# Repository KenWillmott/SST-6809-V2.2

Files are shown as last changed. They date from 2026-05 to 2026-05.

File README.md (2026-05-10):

# SST-6809-V2.2
This is the working repository for the most current and only recommended version of the SST-6809.
It contains all of the files and reference documents, and some documentation. However, the full documentation set will be hosted elsewhere, location is yet to be determined. For now, you can follow the documentation in the old repo "SST-6809" which is mostly concordant with this new version.

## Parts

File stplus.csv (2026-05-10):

Id | Designator | Footprint | Quantity | Designation | Supplier and ref
1 | U10 | DIP-8_W7.62mm_Socket_LongPads | 1 | DS1210
2 | C9,C5,C14,C11,C3,C13,C8,C4,C6,C7 | C_Disc_D8.0mm_W2.5mm_P5.00mm | 10 | 100nF
3 | JP3,JP4,JP1 | PinHeader_1x03_P2.54mm_Vertical | 3 | Jumper_3_Bridged12
4 | U3 | PLCC-32_THT-Socket | 1 | SST39SF010
5 | RN1 | R_Array_SIP9 | 1 | 4.7k
6 | X1 | Oscillator_DIP-8 | 1 | CXO_DIP8
7 | C10 | C_Disc_D9.0mm_W2.5mm_P5.00mm | 1 | 10uF
8 | C1,C2 | C_Disc_D8.0mm_W2.5mm_P5.00mm | 2 | 20pF
9 | U4 | DIP-20_W7.62mm_LongPads | 1 | 74HCT273
10 | J4 | PinHeader_2x03_P2.54mm_Vertical | 1 | Conn_02x03_Odd_Even
11 | Y1 | Crystal_HC18-U_Vertical | 1 | 8.0 MHz
12 | J2 | TerminalBlock_Phoenix_PT-1,5-2-5.0-H_1x02_P5.00mm_Horizontal | 1 | Screw_Terminal_01x02
13 | C12 | C_Disc_D9.0mm_W2.5mm_P5.00mm | 1 | 100nF
14 | H4,H2,H1,H3 | MountingHole_3.2mm_M3_Pad | 4 | MountingHole_Pad
15 | J5 | PinHeader_2x07_P2.54mm_Vertical | 1 | Conn_02x07_Odd_Even
16 | U2 | DIP-24_W15.24mm_LongPads | 1 | MC68B50
17 | U8 | DIP-16_W7.62mm_LongPads | 1 | 74HCT138
18 | R1 | R_Axial_DIN0207_L6.3mm_D2.5mm_P10.16mm_Horizontal | 1 | 10k
19 | JP2 | PinHeader_2x01_P2.54mm_Vertical | 1 | VBAT
20 | D1 | LED_D3.0mm | 1 | STAT
21 | SW1 | SW_PUSH_6mm_H5mm | 1 | Reset
22 | U12 | DIP-16_W7.62mm_LongPads | 1 | 74HCT139
23 | U6 | DIP-32_W15.24mm_LongPads | 1 | AS6C4008-55PCN
24 | J1 | PinHeader_1x06_P2.54mm_Vertical | 1 | Conn_01x06_Pin
25 | J6 | PinSocket_2x20_P2.54mm_Vertical | 1 | Conn_02x20_Odd_Even
26 | U1 | DIP-40_W15.24mm_LongPads | 1 | MC68B09
27 | U9 | TO-92L_Inline | 1 | DS1233
28 | U5 | DIP-14_W7.62mm_LongPads | 1 | 74HCT02
29 | R2 | R_Axial_DIN0207_L6.3mm_D2.5mm_P10.16mm_Horizontal | 1 | 4.7k
30 | D2 | D_DO-35_SOD27_P7.62mm_Horizontal | 1 | 1N4148
31 | U11 | DIP-14_W7.62mm_LongPads | 1 | 74HCT20
32 | J3 | PinHeader_1x04_P2.54mm_Vertical | 1 | Conn_01x04_Pin
33 | U7 | TO-92L_Inline | 1 | DS1813
34 | D3 | LED_D3.0mm | 1 | PWR
35 | BT1 | BatteryHolder_Keystone_103_1x20mm | 1 | 3.0V

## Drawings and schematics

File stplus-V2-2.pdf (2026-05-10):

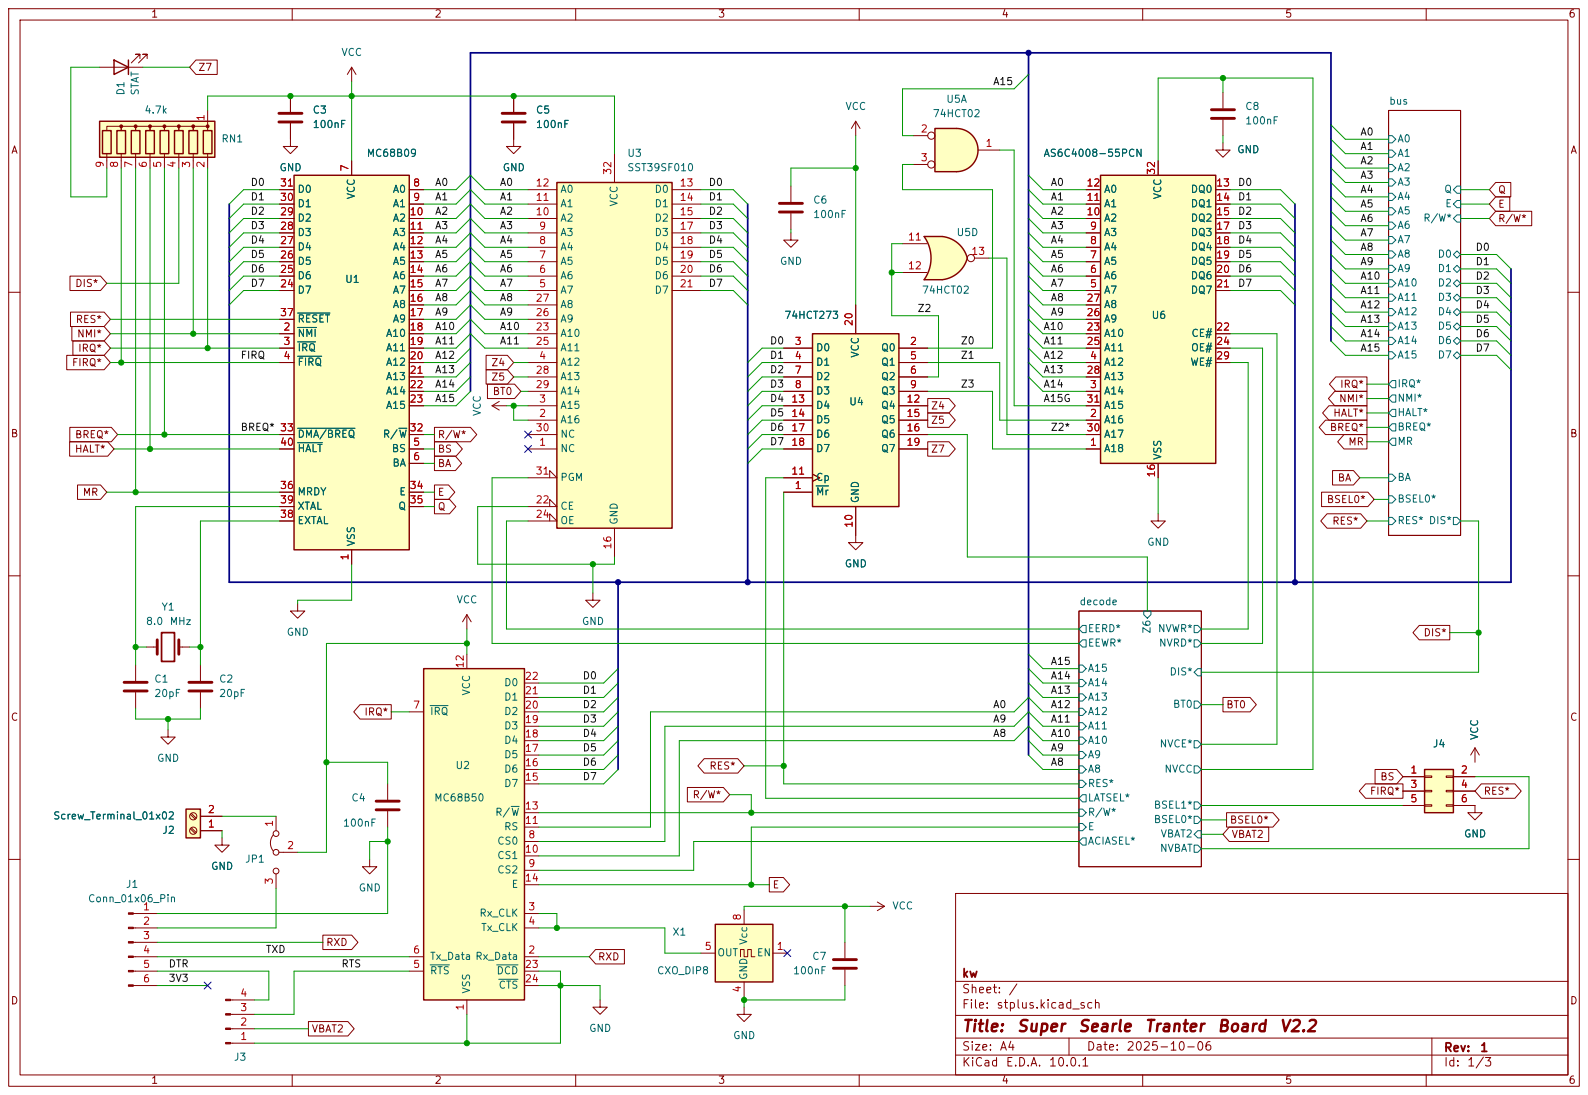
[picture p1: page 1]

Sheet: /
File: stplus.kicad_sch
Title: Super Searle Tranter Board V2.2

Size: A4 | Rev: 1
KiCad E.D.A. 10.0.1 | Id: 1/3

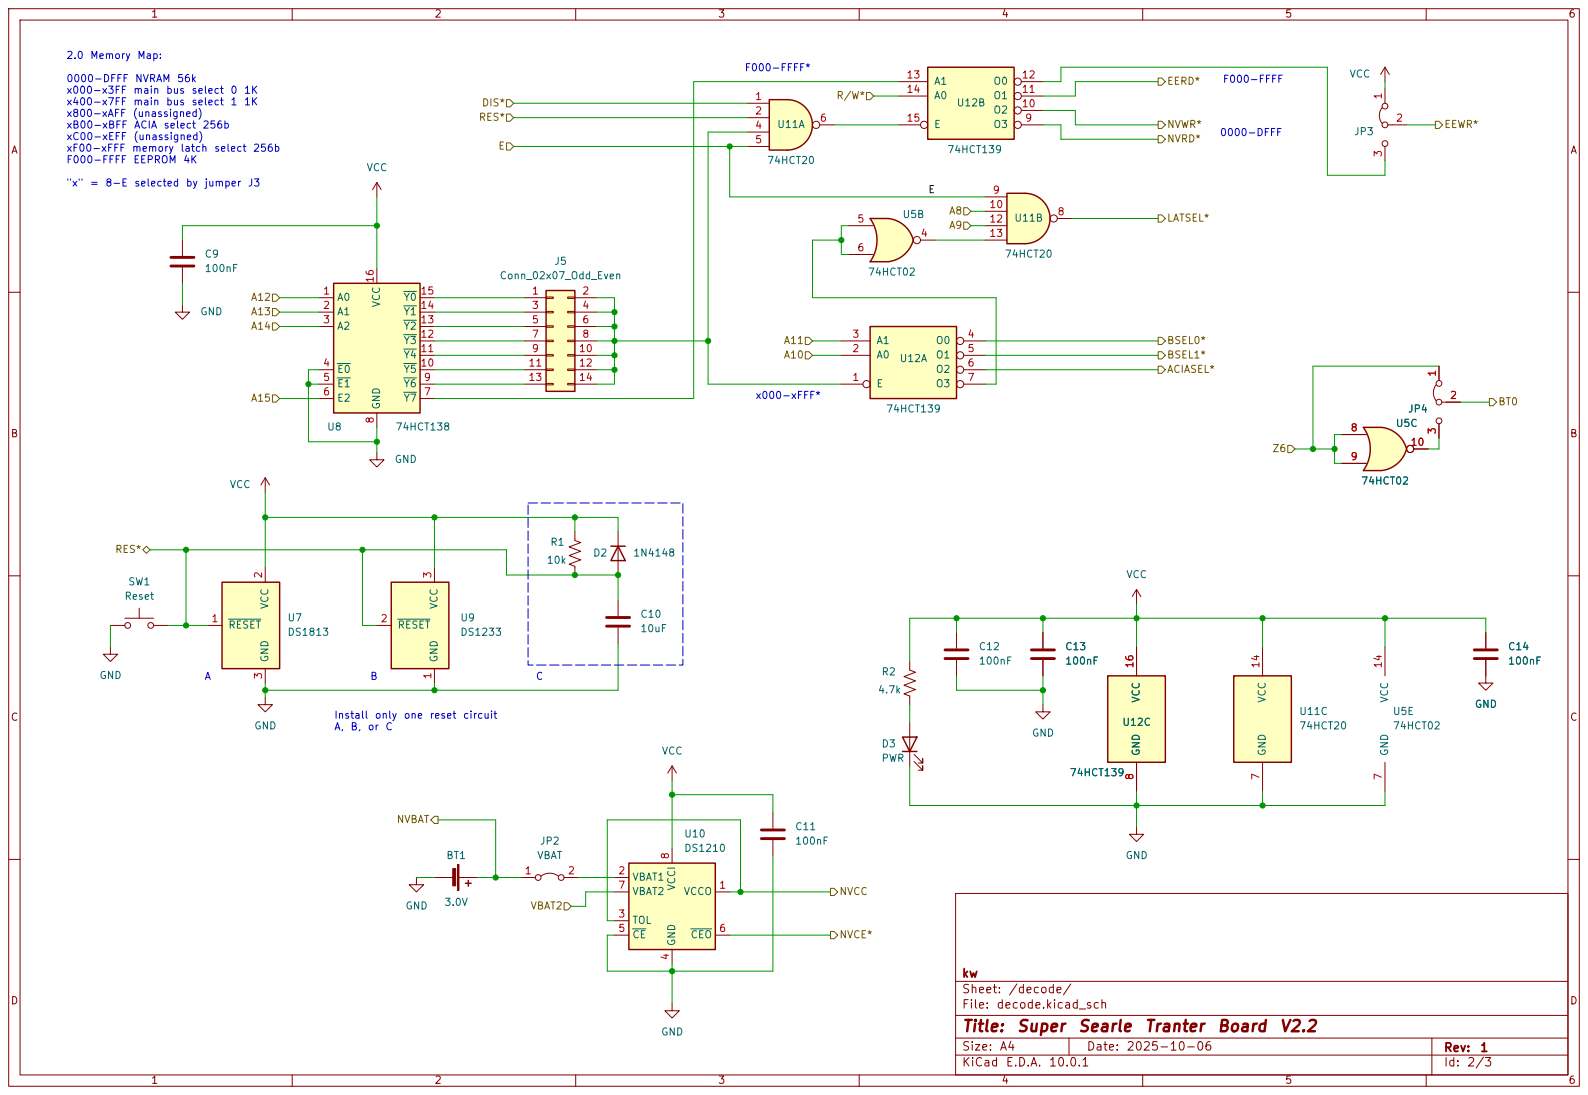
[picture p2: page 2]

2.0 Memory Map: 0000-DFFF NVRAM 56k

x000-x3FF main bus select 0 1K
x400-x7FF main bus select 1 1K
x800-xAFF (unassigned) xB00-xBFF ACIA select 256b

xC00-xEFF (unassigned) xF00-xFFF memory latch select 256b

Install only one reset circuit A, B, or C

Sheet: /decode/
File: decode.kicad_sch
Title: Super Searle Tranter Board V2.2

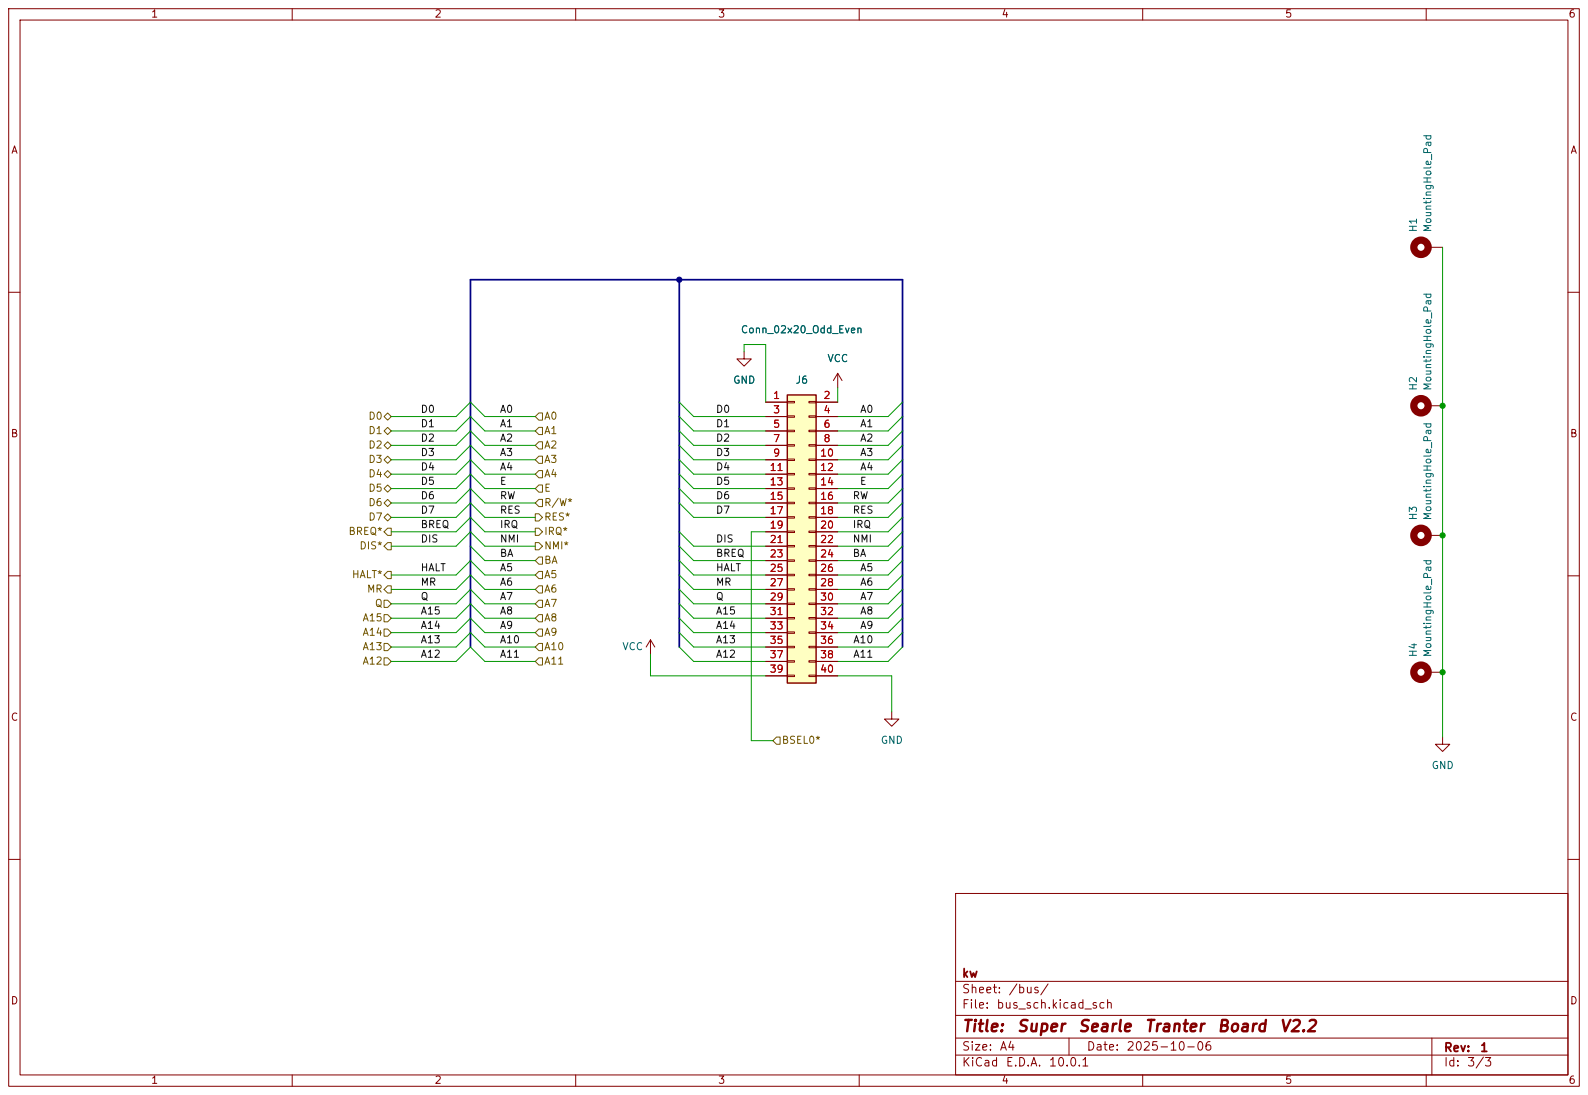
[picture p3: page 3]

Sheet: /bus/
File: bus_sch.kicad_sch
Title: Super Searle Tranter Board V2.2

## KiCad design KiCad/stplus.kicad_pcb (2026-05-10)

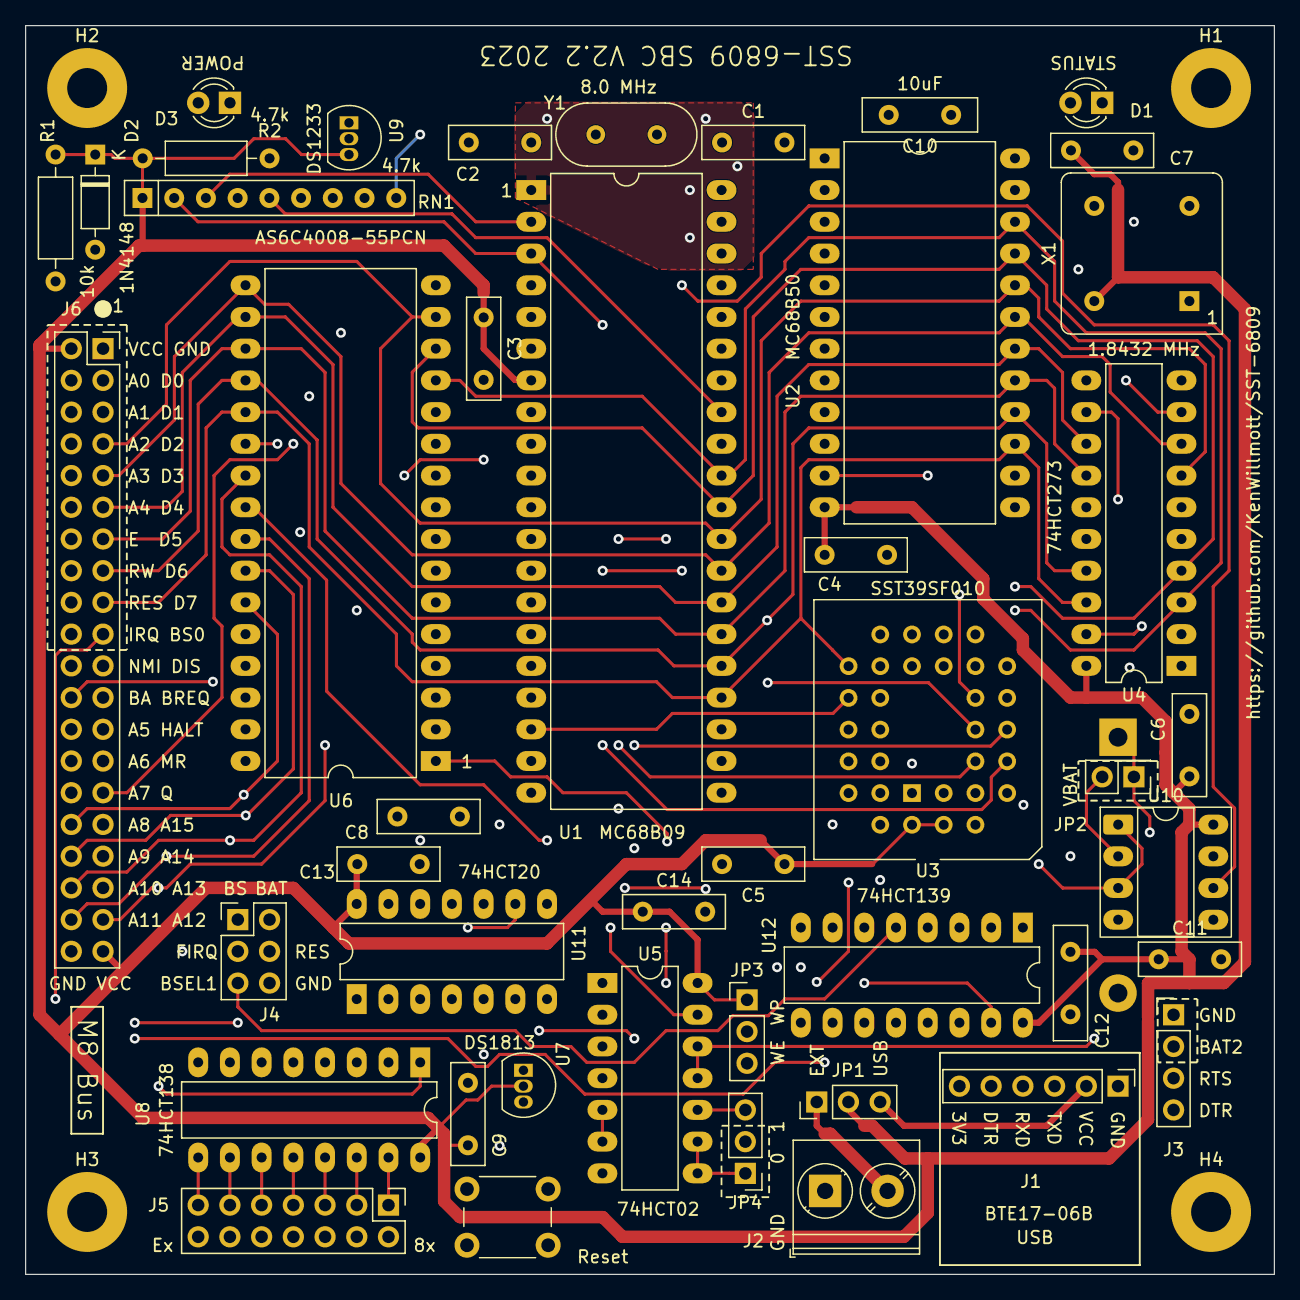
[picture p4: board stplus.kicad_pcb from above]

Board: 4 copper layers, 100.0 x 100.0 mm, 50 parts (1 on the bottom side), 88 nets.

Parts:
BT1: 3.0V; BatteryHolder_Keystone_103_1x20mm
C1, C2: 20pF; C_Disc_D8.0mm_W2.5mm_P5.00mm
C3, C4, C5, C6, C7, C8, C9, C11, C13, C14: 100nF; C_Disc_D8.0mm_W2.5mm_P5.00mm
C10: 10uF; C_Disc_D9.0mm_W2.5mm_P5.00mm
C12: 100nF; C_Disc_D9.0mm_W2.5mm_P5.00mm
D1: STAT; LED_D3.0mm
D2: 1N4148; D_DO-35_SOD27_P7.62mm_Horizontal
D3: PWR; LED_D3.0mm
H1, H2, H3, H4: MountingHole_Pad; MountingHole_3.2mm_M3_Pad
J1: Conn_01x06_Pin; PinHeader_1x06_P2.54mm_Vertical
J2: Screw_Terminal_01x02; TerminalBlock_Phoenix_PT-1,5-2-5.0-H_1x02_P5.00mm_Horizontal
J3: Conn_01x04_Pin; PinHeader_1x04_P2.54mm_Vertical
J4: Conn_02x03_Odd_Even; PinHeader_2x03_P2.54mm_Vertical
J5: Conn_02x07_Odd_Even; PinHeader_2x07_P2.54mm_Vertical
J6: Conn_02x20_Odd_Even; PinSocket_2x20_P2.54mm_Vertical
JP1, JP3, JP4: Jumper_3_Bridged12; PinHeader_1x03_P2.54mm_Vertical
JP2: VBAT; PinHeader_2x01_P2.54mm_Vertical
R1: 10k; R_Axial_DIN0207_L6.3mm_D2.5mm_P10.16mm_Horizontal
R2: 4.7k; R_Axial_DIN0207_L6.3mm_D2.5mm_P10.16mm_Horizontal
RN1: 4.7k; R_Array_SIP9
SW1: Reset; SW_PUSH_6mm_H5mm
U1: MC68B09; DIP-40_W15.24mm_LongPads
U2: MC68B50; DIP-24_W15.24mm_LongPads
U3: SST39SF010; PLCC-32_THT-Socket
U4: 74HCT273; DIP-20_W7.62mm_LongPads
U5: 74HCT02; DIP-14_W7.62mm_LongPads
U6: AS6C4008-55PCN; DIP-32_W15.24mm_LongPads
U7: DS1813; TO-92L_Inline
U8: 74HCT138; DIP-16_W7.62mm_LongPads
U9: DS1233; TO-92L_Inline
U10: DS1210; DIP-8_W7.62mm_Socket_LongPads
U11: 74HCT20; DIP-14_W7.62mm_LongPads
U12: 74HCT139; DIP-16_W7.62mm_LongPads
X1: CXO_DIP8; Oscillator_DIP-8
Y1: 8.0 MHz; Crystal_HC18-U_Vertical

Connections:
/A0: J6.4, U1.8 (A0), U2.11 (RS), U3.12 (A0), U6.12 (A0)
/A1: J6.6, U1.9 (A1), U3.11 (A1), U6.11 (A1)
/A2: J6.8, U1.10 (A2), U3.10 (A2), U6.10 (A2)
/A3: J6.10, U1.11 (A3), U3.9 (A3), U6.9 (A3)
/A4: J6.12, U1.12 (A4), U3.8 (A4), U6.8 (A4)
/A5: J6.26, U1.13 (A5), U3.7 (A5), U6.7 (A5)
/A6: J6.28, U1.14 (A6), U3.6 (A6), U6.6 (A6)
/A7: J6.30, U1.15 (A7), U3.5 (A7), U6.5 (A7)
/A8: J6.32, U1.16 (A8), U2.10 (CS1), U3.27 (A8), U6.27 (A8), U11.10
/A9: J6.34, U1.17 (A9), U2.8 (CS0), U3.26 (A9), U6.26 (A9), U11.12
/A10: J6.36, U1.18 (A10), U3.23 (A10), U6.23 (A10), U12.2 (A0)
/A11: J6.38, U1.19 (A11), U3.25 (A11), U6.25 (A11), U12.3 (A1)
/A12: J6.37, U1.20 (A12), U6.4 (A12), U8.1 (A0)
/A13: J6.35, U1.21 (A13), U6.28 (A13), U8.2 (A1)
/A14: J6.33, U1.22 (A14), U6.3 (A14), U8.3 (A2)
/A15: J6.31, U1.23 (A15), U5.2, U8.6 (E2)
/A15G: U5.1, U6.31 (A15)
/D0: J6.3, U1.31 (D0), U2.22 (D0), U3.13 (D0), U4.3 (D0), U6.13 (DQ0)
/D1: J6.5, U1.30 (D1), U2.21 (D1), U3.14 (D1), U4.4 (D1), U6.14 (DQ1)
/D2: J6.7, U1.29 (D2), U2.20 (D2), U3.15 (D2), U4.7 (D2), U6.15 (DQ2)
/D3: J6.9, U1.28 (D3), U2.19 (D3), U3.17 (D3), U4.8 (D3), U6.17 (DQ3)
/D4: J6.11, U1.27 (D4), U2.18 (D4), U3.18 (D4), U4.13 (D4), U6.18 (DQ4)
/D5: J6.13, U1.26 (D5), U2.17 (D5), U3.19 (D5), U4.14 (D5), U6.19 (DQ5)
/D6: J6.15, U1.25 (D6), U2.16 (D6), U3.20 (D6), U4.17 (D6), U6.20 (DQ6)
/D7: J6.17, U1.24 (D7), U2.15 (D7), U3.21 (D7), U4.18 (D7), U6.21 (DQ7)
/DTR: J1.5, J3.4
/RTS: J3.3, U2.5 (~RTS)
/TXD: J1.4, U2.6 (Tx_Data)
/Z0: U4.2 (Q0), U5.3
/Z1: U4.5 (Q1), U6.2 (A16)
/Z2: U4.6 (Q2), U5.11, U5.12
/Z2*: U5.13, U6.30 (A17)
/Z3: U4.9 (Q3), U6.1 (A18)
/decode/ACIASEL*: U2.9 (CS2), U12.6 (O2)
/decode/BSEL1*: J4.5, U12.5 (O1)
/decode/EERD*: U3.24 (OE), U12.11 (O1)
/decode/EEWR*: JP3.2 (C), U3.31 (PGM)
/decode/LATSEL*: U4.11 (Cp), U11.8
/decode/NVBAT: BT1.1 (+), J4.2, JP2.1 (A)
/decode/NVCC: C8.1, U6.32 (VCC), U10.1 (VCCO), U10.3 (TOL)
/decode/NVCE*: U6.22 (CE#), U10.6 (~CEO)
/decode/NVRD*: U6.24 (OE#), U12.9 (O3)
/decode/NVWR*: U6.29 (WE#), U12.10 (O2)
/decode/Z6: JP4.1 (A), U4.16 (Q6), U5.8, U5.9
BA: J6.24, U1.6 (BA)
BREQ*: J6.23, RN1.5 (R4), U1.33 (~DMA/BREQ)
BS: J4.1, U1.5 (BS)
BSEL0*: J6.19, U12.4 (O0)
BT0: JP4.2 (C), U3.29 (A14)
DIS*: J6.21, RN1.4 (R3), U11.1
E: J6.14, U1.34 (E), U2.14 (E), U11.5, U11.9
FIRQ*: J4.3, RN1.8 (R7), U1.4 (~FIRQ)
GND: BT1.2 (-), C1.2, C2.2, C3.2, C4.2, C5.2, C6.2, C7.1, C8.2, C9.2, C10.2, C11.2, C12.2, C13.2, C14.2, D3.1 (K), H1.1, H2.1, H3.1, H4.1, J1.1, J2.1, J3.1, J4.6, J6.1, J6.40, SW1.2, U1.1 (VSS), U2.1 (VSS), U2.23 (~DCD), U2.24 (~CTS), U3.16 (GND), U3.22 (CE), U4.10 (GND), U5.7 (GND), U6.16 (VSS), U7.3 (GND), U8.4 (~E0), U8.5 (~E1), U8.8 (GND), U9.1 (GND), U10.4 (GND), U10.5 (~CE), U11.7 (GND), U12.8 (GND), X1.4 (GND)
HALT*: J6.25, RN1.6 (R5), U1.40 (~HALT)
IRQ*: J6.20, RN1.2 (R1), U1.3 (~IRQ), U2.7 (~IRQ)
MR: J6.27, RN1.7 (R6), U1.36 (MRDY)
NMI*: J6.22, RN1.3 (R2), U1.2 (~NMI)
unnamed: D1.2 (A), RN1.9 (R8)
unnamed: D3.2 (A), R2.2
unnamed: J1.2, JP1.3 (B)
unnamed: J2.2, JP1.1 (A)
unnamed: J5.1, U8.15 (~Y0)
unnamed: J5.3, U8.14 (~Y1)
unnamed: J5.5, U8.13 (~Y2)
unnamed: J5.7, U8.12 (~Y3)
unnamed: J5.9, U8.11 (~Y4)
unnamed: J5.2, J5.4, J5.6, J5.8, J5.10, J5.12, J5.14, U11.4, U12.1 (E)
unnamed: J5.11, U8.10 (~Y5)
unnamed: J5.13, U8.9 (~Y6)
unnamed: JP2.2 (B), U10.2 (VBAT1)
unnamed: JP3.3 (B), U12.12 (O0)
unnamed: JP4.3 (B), U5.10
unnamed: C2.1, U1.38 (EXTAL), Y1.2
unnamed: C1.1, U1.39 (XTAL), Y1.1
unnamed: U2.3 (Rx_CLK), U2.4 (Tx_CLK), X1.5 (OUT)
unnamed: U5.4, U11.13
unnamed: U5.5, U5.6, U12.7 (O3)
unnamed: U8.7 (~Y7), U12.13 (A1)
unnamed: U11.6, U12.15 (E)
Q: J6.29, U1.35 (Q)
RES*: C10.1, D2.2 (A), J4.4, J6.18, R1.2, SW1.1, U1.37 (~RESET), U4.1 (~Mr), U7.1 (~RESET), U9.2 (~RESET), U11.2
RXD: J1.3, U2.2 (Rx_Data)
R/W*: J6.16, U1.32 (R/~W), U2.13 (R/~W), U12.14 (A0)
VBAT2: J3.2, U10.7 (VBAT2)
VCC: C3.1, C4.1, C5.1, C6.1, C7.2, C9.1, C11.1, C12.1, C13.1, C14.1, D2.1 (K), J6.2, J6.39, JP1.2 (C), JP3.1 (A), R1.1, R2.1, RN1.1 (common), U1.7 (VCC), U2.12 (VCC), U3.2 (A16), U3.3 (A15), U3.32 (VCC), U4.20 (VCC), U5.14 (VCC), U7.2 (VCC), U8.16 (VCC), U9.3 (VCC), U10.8 (VCCI), U11.14 (VCC), U12.16 (VCC), X1.8 (Vcc)
Z4: U3.4 (A12), U4.12 (Q4)
Z5: U3.28 (A13), U4.15 (Q5)
Z7: D1.1 (K), U4.19 (Q7)

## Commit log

2026-05-10 exported schematic
2026-05-10 add BOM
    [stplus.csv]
2026-05-13 interactive BOM
